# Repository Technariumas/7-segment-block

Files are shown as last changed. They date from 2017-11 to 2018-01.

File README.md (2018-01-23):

# 7-segment-block

A big 7 segment plug and play module designed to be easily chainable and be driven by SPI bus.

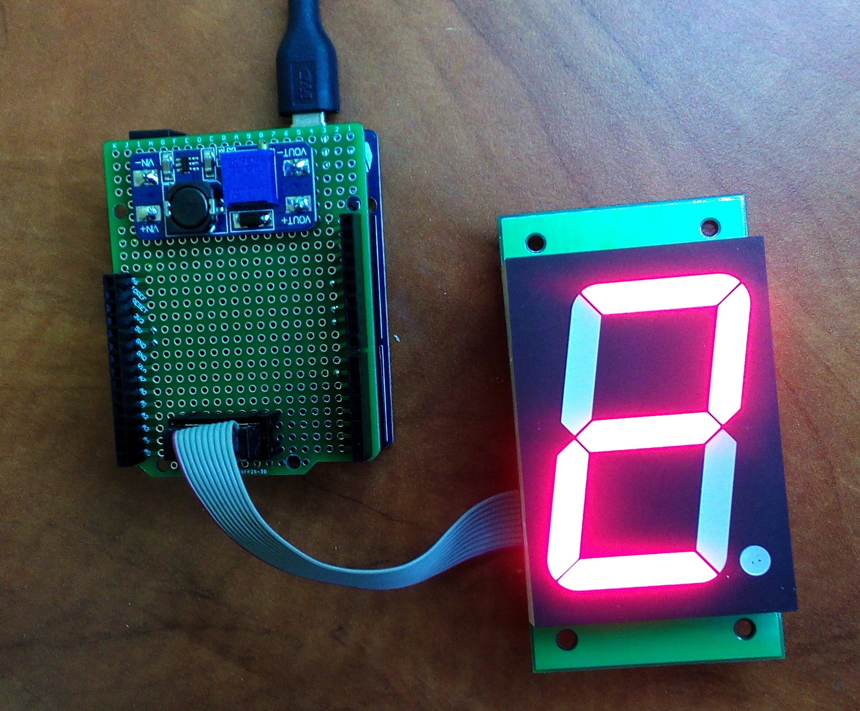
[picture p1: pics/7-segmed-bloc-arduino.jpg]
arduino


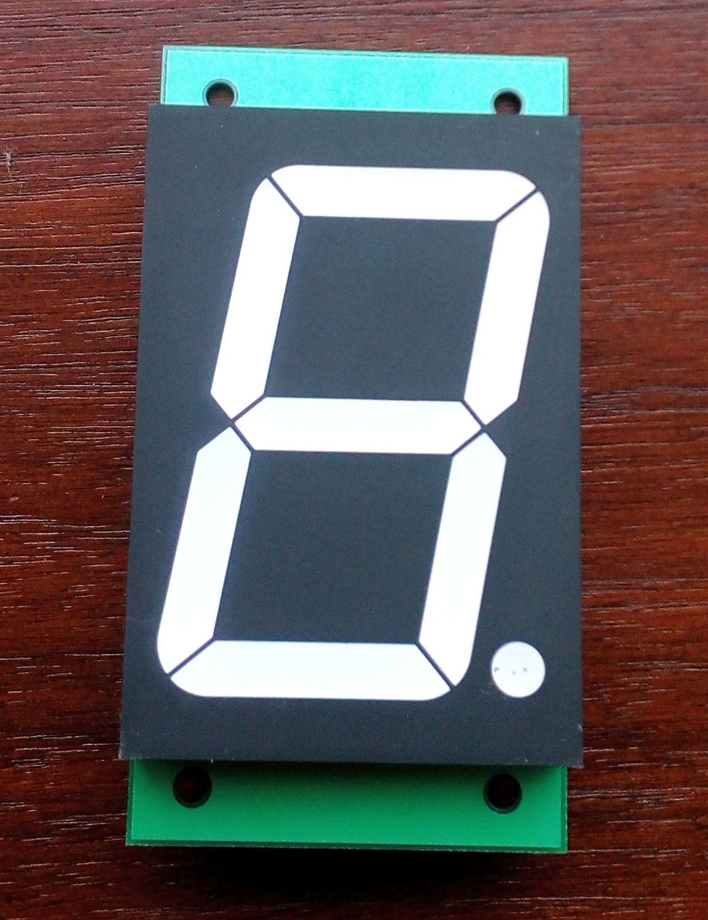
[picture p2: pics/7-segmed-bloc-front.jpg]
front


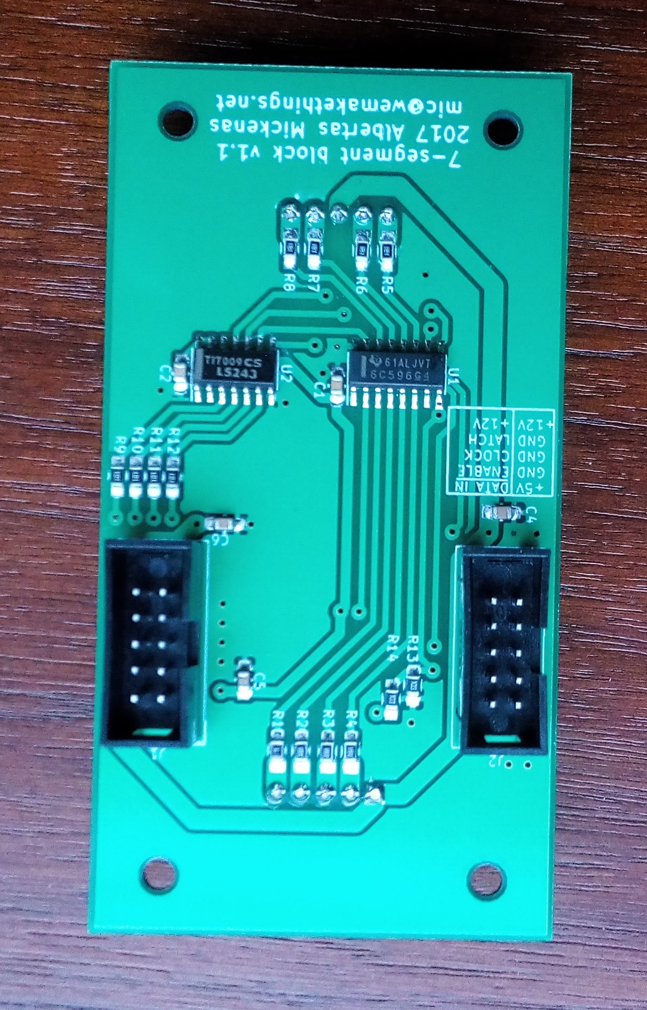
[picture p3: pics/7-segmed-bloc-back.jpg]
back


```Arduino
#include<SPI.h>
#include <Bounce2.h>

#define ZERO  0b11101110
#define ONE   0b10000010
#define TWO   0b11011100
#define THREE 0b11010110
#define FOUR  0b10110010
#define FIVE  0b01110110
#define SIX   0b01111110
#define SEVEN 0b11000010
#define EIGHT 0b11111110
#define NINE  0b11110110
#define DARK  0b00000000

uint8_t digits[] = {ZERO, ONE, TWO, THREE, FOUR, FIVE, SIX, SEVEN, EIGHT, NINE, DARK};
uint8_t brightness = 0;

void setup() {
  Serial.begin(9600);
  randomSeed(analogRead(0));
  
  //Output enable
  pinMode(6, OUTPUT);  
  digitalWrite(6, HIGH);
 
  //Latch
  pinMode(10, OUTPUT);
  digitalWrite(10, HIGH);
 
  //MOSI
  pinMode(11, OUTPUT);
  
  //SCK
  pinMode(13, OUTPUT);

  SPI.begin();
  SPI.setDataMode(SPI_MODE0);
  digitalWrite(6, LOW);  
}

void displayDigit(uint8_t digit1) {
    digitalWrite(10, LOW);
    SPI.transfer(digit1);
    digitalWrite(10, HIGH);  
}

uint8_t i = 0;

void loop() {
  displayDigit(digits[i]);
  i++;
  if(i > 9) {
    i = 0; 
  }
  while(brightness++ < 254) {
    analogWrite(6, brightness++);
    delay(10);   
  }
  brightness = 0;
  delay(10);
}

```

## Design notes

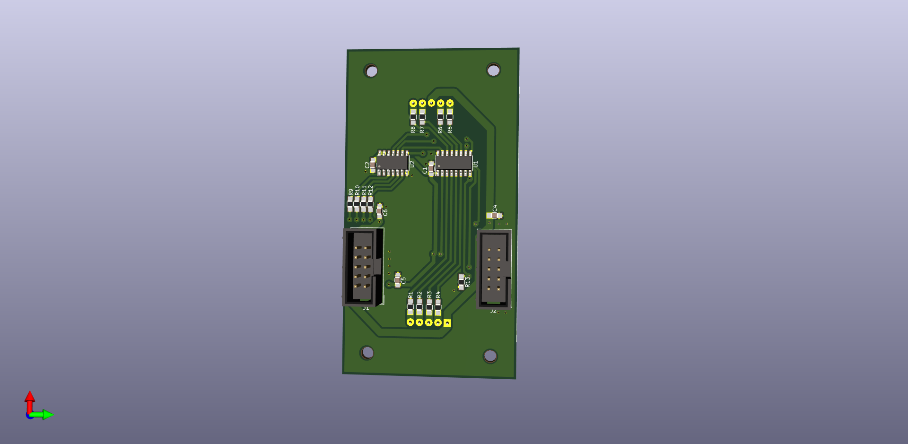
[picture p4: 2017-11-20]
7-segment-block-back.png

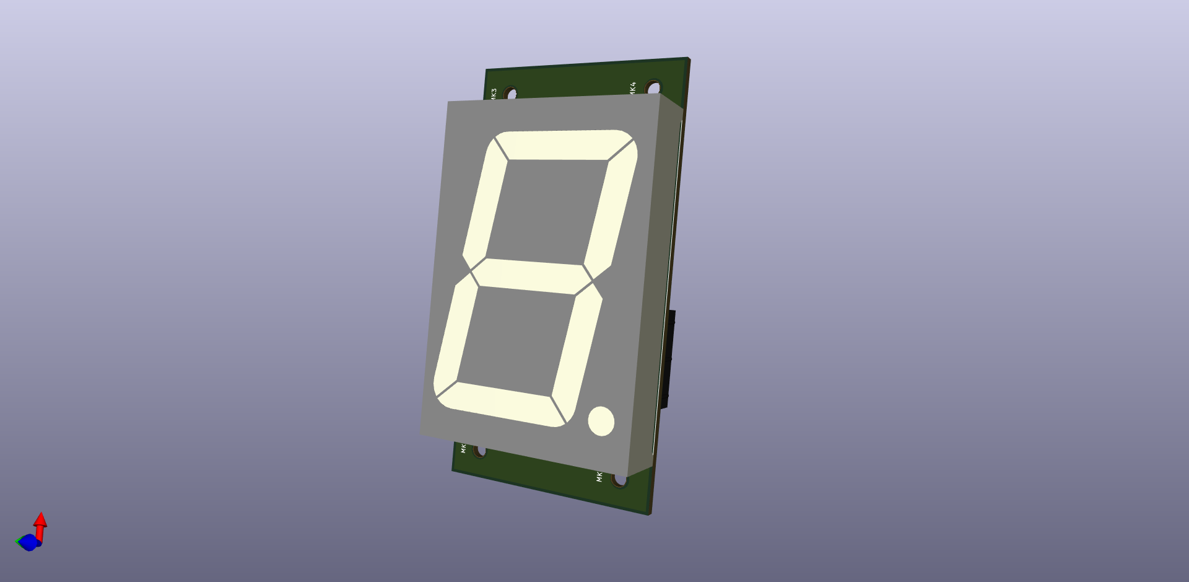
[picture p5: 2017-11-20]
7-segment-block.png

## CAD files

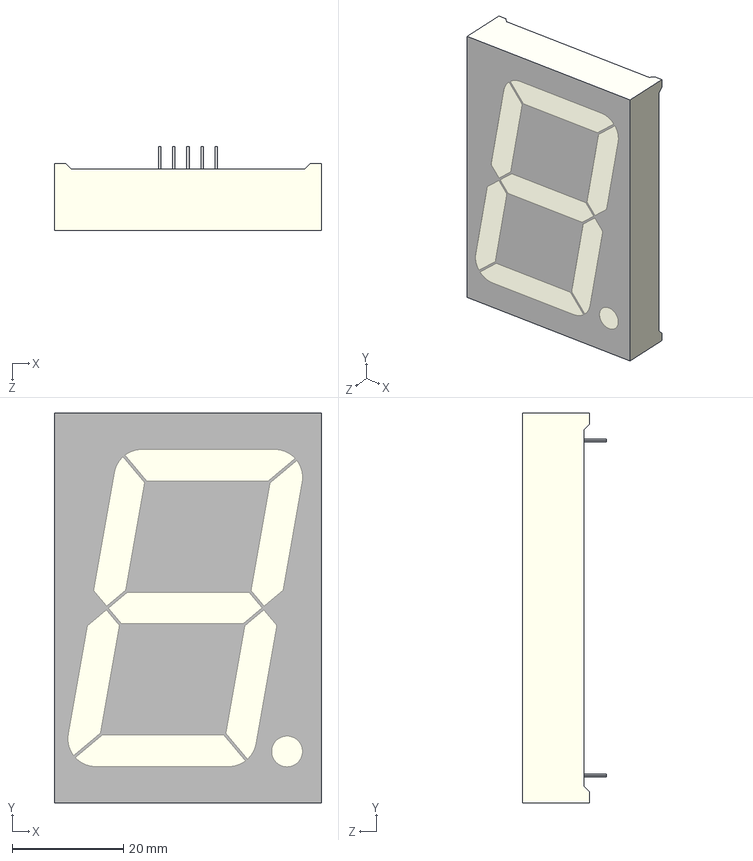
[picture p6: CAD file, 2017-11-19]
3d/User Library-SA23-11.STEP
48.0 x 70.0 x 15.0 mm

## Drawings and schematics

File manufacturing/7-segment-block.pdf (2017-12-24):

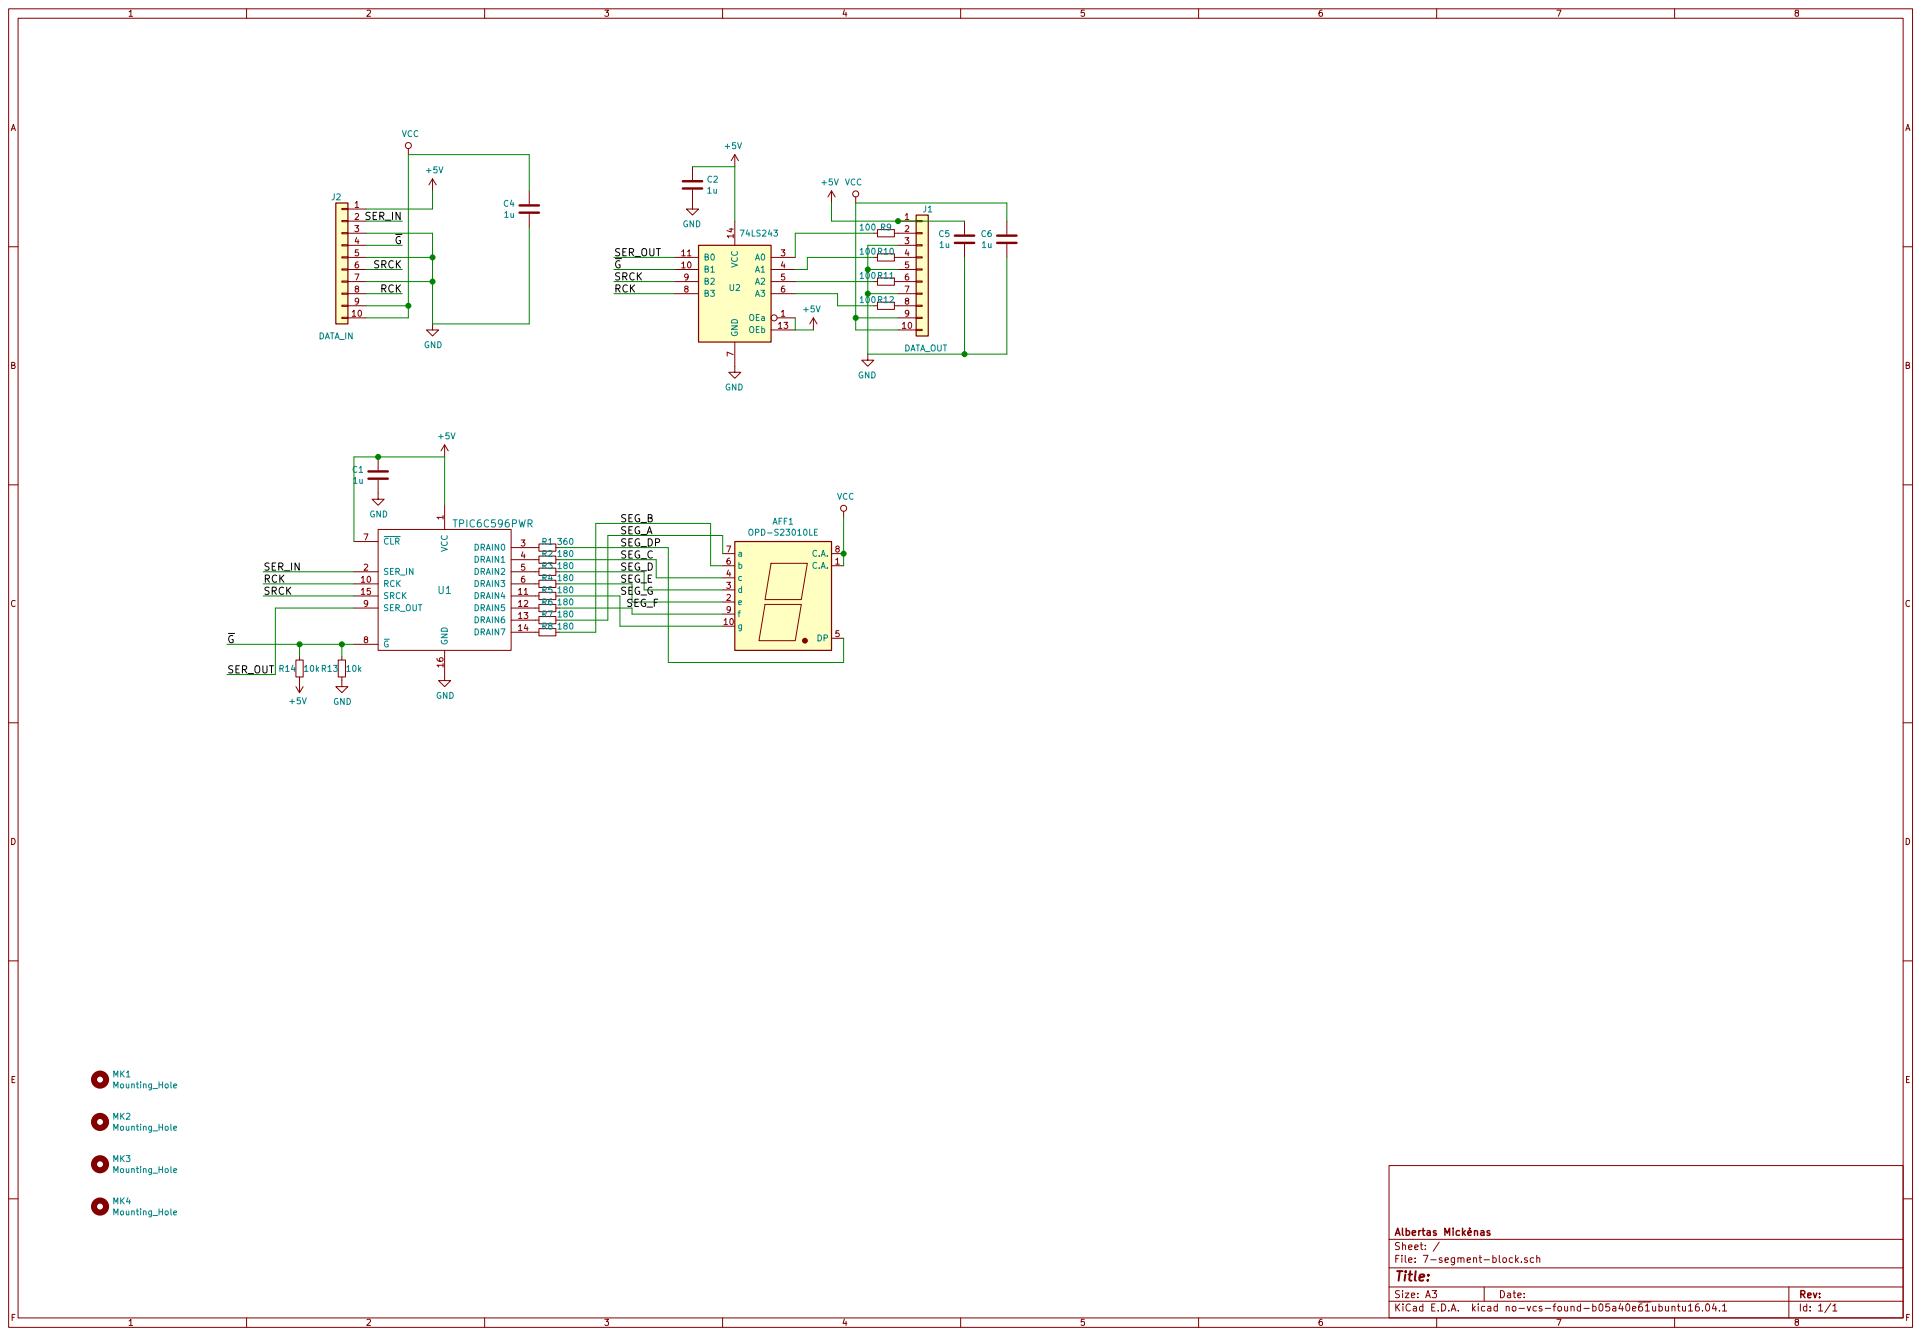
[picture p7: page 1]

SEG_A
SEG_DP

SEG_D

SEG_G

File: 7-segment-block.sch Sheet: / Albertas Micknas

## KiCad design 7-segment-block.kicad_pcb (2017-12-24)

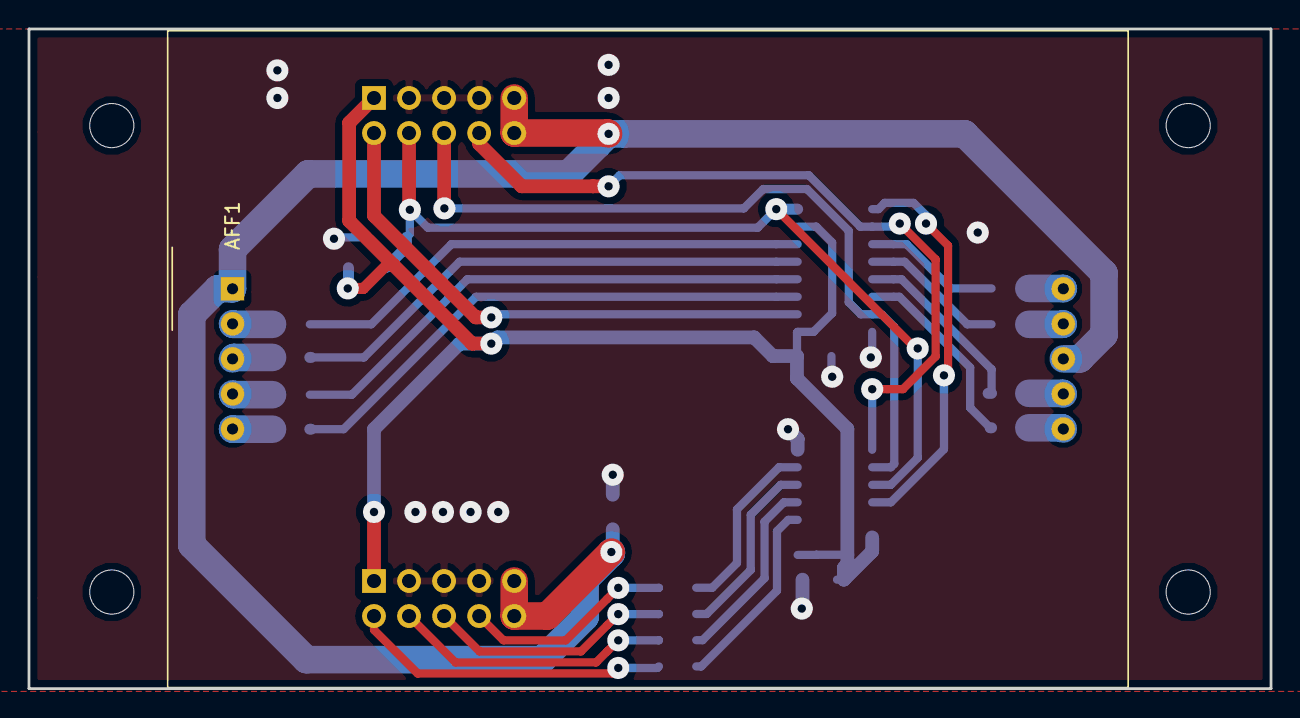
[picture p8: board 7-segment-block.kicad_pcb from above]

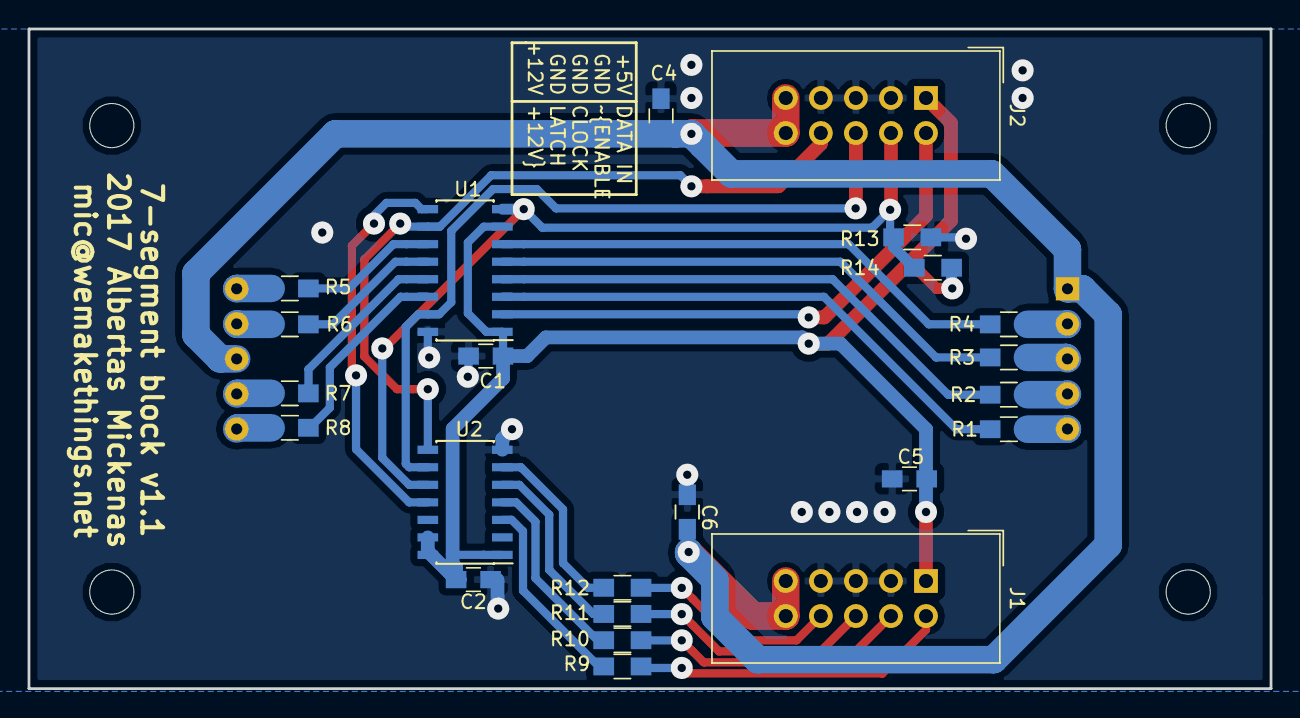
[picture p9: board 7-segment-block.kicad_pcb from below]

Board: 2 copper layers, 90.0 x 47.8 mm, 28 parts (23 on the bottom side), 32 nets.

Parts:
AFF1: OPD-S23010LE; SBC18-11SURKCGKWA
C1, C2, C4, C5, C6: C; C_0805_HandSoldering
J1: DATA_OUT; IDC-Header_2x05_Pitch2.54mm_Straight
J2: DATA_IN; IDC-Header_2x05_Pitch2.54mm_Straight
MK1, MK2, MK3, MK4: Mounting_Hole; MountingHole_3.2mm_M3
R1: 90; R_0805_HandSoldering
R2, R3, R4, R5, R6, R7, R8: 180; R_0805_HandSoldering
R9, R10, R11, R12: 100; R_0805_HandSoldering
R13, R14: 10k; R_0805_HandSoldering
U1: TPIC6C596PWR; SOIC-16_3.9x9.9mm_Pitch1.27mm
U2: 74LS243; SOIC-14_3.9x8.7mm_Pitch1.27mm

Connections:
+5V: C1.1, C2.1, C5.1, J1.1, J2.1, R14.2, U1.1, U1.7, U2.1, U2.13, U2.14
/RCK: J2.8, U1.10, U2.8
/SEG_A: AFF1.7, R7.1
/SEG_B: AFF1.6, R8.1
/SEG_C: AFF1.4, R2.1
/SEG_D: AFF1.3, R3.1
/SEG_DP: AFF1.5, R1.1
/SEG_E: AFF1.2, R4.1
/SEG_F: AFF1.9, R6.1
/SEG_G: AFF1.10, R5.1
/SER_IN: J2.2, U1.2
/SER_OUT: U1.9, U2.11
/SRCK: J2.6, U1.15, U2.9
/~G: J2.4, R13.1, R14.1, U1.8, U2.10
GND: C1.2, C2.2, C4.2, C5.2, C6.2, J1.3, J1.5, J1.7, J2.3, J2.5, J2.7, R13.2, U1.16, U2.7
unnamed: J1.2, R9.2
unnamed: J1.4, R10.2
unnamed: J1.6, R11.2
unnamed: J1.8, R12.2
unnamed: R1.2, U1.3
unnamed: R2.2, U1.4
unnamed: R3.2, U1.5
unnamed: R4.2, U1.6
unnamed: R5.2, U1.11
unnamed: R6.2, U1.12
unnamed: R7.2, U1.13
unnamed: R8.2, U1.14
unnamed: R9.1, U2.3
unnamed: R10.1, U2.4
unnamed: R11.1, U2.5
unnamed: R12.1, U2.6
VCC: AFF1.1, AFF1.8, C4.1, C6.1, J1.9, J1.10, J2.9, J2.10

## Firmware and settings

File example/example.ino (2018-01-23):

#include<SPI.h>
#include <Bounce2.h>

#define ZERO  0b11101110
#define ONE   0b10000010
#define TWO   0b11011100
#define THREE 0b11010110
#define FOUR  0b10110010
#define FIVE  0b01110110
#define SIX   0b01111110
#define SEVEN 0b11000010
#define EIGHT 0b11111110
#define NINE  0b11110110
#define DARK  0b00000000

uint8_t digits[] = {ZERO, ONE, TWO, THREE, FOUR, FIVE, SIX, SEVEN, EIGHT, NINE, DARK};
uint8_t brightness = 0;

void setup() {
  Serial.begin(9600);
  randomSeed(analogRead(0));
  
  pinMode(6, OUTPUT);
  digitalWrite(6, HIGH);
  pinMode(10, OUTPUT);
  digitalWrite(10, HIGH);
  pinMode(11, OUTPUT);
  pinMode(13, OUTPUT);

  SPI.begin();
  SPI.setDataMode(SPI_MODE0);
  digitalWrite(6, LOW);  
}

unsigned int get_tens(unsigned int num) {
  unsigned int tens = 0;
  if (num == 100) {
    tens = 9;
  }
  else if (num == 0) {
    tens = 10;
  }
  else {
    tens = num/10;
  }
  return tens;  
}

unsigned int get_single_digits(unsigned int num) {
  unsigned int sd = 0;
  if (num == 100) {
    sd = 9;
  }
  else {
    sd = num % 10;
  }
  return sd;
}


void displayDigits(uint8_t digit1, uint8_t digit2, uint8_t digit3, uint8_t digit4, uint8_t digit5, uint8_t digit6) {
    digitalWrite(10, LOW);
    SPI.transfer(digit1);
    SPI.transfer(digit2);
    SPI.transfer(digit3);
    SPI.transfer(digit4);  
    SPI.transfer(digit5);
    SPI.transfer(digit6);   
    digitalWrite(10, HIGH);  
}

void displayDigit(uint8_t digit1) {
    digitalWrite(10, LOW);
    SPI.transfer(digit1);
    digitalWrite(10, HIGH);  
}

uint8_t i = 0;

void loop() {
  displayDigit(digits[i]);
  i++;
  if(i > 9) {
    i = 0; 
  }
  while(brightness++ < 254) {
    analogWrite(6, brightness++);
    delay(10);   
  }
  brightness = 0;
  delay(10);
}

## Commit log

2017-11-19 Start schematics, start PCB
    [7-segment-block.kicad_pcb, 7-segment-block.sch, User Library-SA23-11.STEP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]
2017-11-19 Add mounting holes, dropper resistors and a buffer
    [7-segment-block.kicad_pcb, 7-segment-block.sch]
2017-11-19 Add terminator resistors
    [7-segment-block.kicad_pcb, 7-segment-block.sch]
2017-11-19 Start routing, maybe change to a different buffer that has a more friendly pin location
    [7-segment-block.kicad_pcb, 7-segment-block.sch]
2017-11-20 Finish routing, change buffer IC, add some decoupling caps
    [7-segment-block.kicad_pcb, 7-segment-block.sch]
2017-11-20 Change orientation of cap to mitigate bendring problems. Add dimensions and hole markers
    [7-segment-block.kicad_pcb]
2017-12-24 Add pullup on ~G, send for manufacturing
    [7-segment-block-B.Cu.gbr, 7-segment-block-B.Mask.gbr, 7-segment-block-B.Paste.gbr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]
2017-12-24 Add some lincence notices
    [7-segment-block.kicad_pcb, 7-segment-block.sch]

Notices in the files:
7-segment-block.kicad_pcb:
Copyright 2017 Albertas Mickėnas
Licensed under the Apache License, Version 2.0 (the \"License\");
